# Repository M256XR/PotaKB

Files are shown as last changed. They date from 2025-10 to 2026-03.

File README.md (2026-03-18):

# PotaKB

XIAO nRF52840ベースのワイヤレスキーボード・マウス複合デバイス。

## 概要

- **MCU**: Seeed XIAO nRF52840
- **キー数**: 65キー（8×8マトリクス × MCP23017 + 直接接続2キー）
- **接続**: Bluetooth LE（3スロット独立切替）/ USB HID
- **スティック**: アナログスティックによるマウス操作・スクロール（EMAスムージング）
- **設定**: Web Configuratorからリアルタイム書き換え（BLE / USB Serial）

## 主な機能

### Bluetooth
- **3スロット独立接続**（PotaKB-1 / PotaKB-2 / PotaKB-3）
  - スロットごとに固有のBLEアドレスとボンドDBを持つ → 同一PCで複数スロット使用可
  - スロット別LEDカラー：BT1=青 / BT2=水色 / BT3=マゼンタ
- **高速通信**: `BANDWIDTH_MAX`（hvn_qsize=3）+ 接続インターバル7.5ms → 約500Hz
- BT中にUSBを刺すと自動でUSBモードに切替

### USB
- HID Resolution Multiplier対応（対応OSで高精度スクロール）
- VID=`0x239A` / PID=`0x8029`

### その他
- 一定時間無操作でLEDオフ（スリープ）、操作で即復帰
- バッテリー残量通知（BLE Battery Service）
- フラッシュへのキーマップ・設定の永続保存

## ディレクトリ構成

```
program/PotaKB_fw/
├── PotaKB_fw.ino          ファームウェア (Arduino / nRF52 core)
├── keymap.h               キーマップ定義・デフォルト設定値
└── PotaKB_Configurator/   Web設定ツール (BLE + USB Serial対応)
    ├── index.html
    ├── style.css
    └── script.js

tools/
├── .arduino-user/         カスタムライブラリ（改造済み Bluefruit52Lib）
├── build.ps1              ビルドスクリプト
├── flash.ps1              フラッシュスクリプト
├── setup.ps1              環境セットアップ
└── arduino-cli.yaml       arduino-cli設定

kicad/                     KiCAD回路図・PCBデータ
stl/                       3Dプリント用STLモデル
SPEC.md                    ファームウェア仕様書
```

## ビルド環境

arduino-cli を使用（Arduino IDE不要）。

### 初回セットアップ

```
tools/1_setup.bat
```

ボードパッケージ（Seeeduino nRF52）と依存ライブラリを自動インストール。

### ビルド・フラッシュ

```
tools/2_build.bat   # コンパイル
tools/3_flash.bat   # USB Serial DFUでフラッシュ
```

### 依存ライブラリ（tools/.arduino-user/libraries に同梱）

- `Bluefruit52Lib`（スロット別ボンドDB対応に改造）
- `Adafruit_MCP23017_Arduino_Library`
- `Adafruit_BusIO`

## Configuratorの使い方

`program/PotaKB_fw/PotaKB_Configurator/index.html` をブラウザ（Chrome / Edge）で開く。

- **Bluetooth接続**: デバイス名 `PotaKB-1` / `PotaKB-2` / `PotaKB-3` で接続
- **USB Serial接続**: VID=`0x239A` / PID=`0x8029` で接続
- キーをクリックして選択し、パレットまたはキー入力で割り当て
- 接続時にバッテリー残量を自動取得

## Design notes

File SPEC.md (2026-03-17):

# PotaKB v2.0 ファームウェア仕様書

## 1. ハードウェア構成（固定）

### MCU
- **XIAO nRF52840** (Arm Cortex-M4, nRF52840)

### ピン配置

| 機能 | ピン | 備考 |
|---|---|---|
| スティック（物理X軸） | A2 | PCBミスによりY動作として扱う |
| スティック（物理Y軸） | A3 | PCBミスによりX動作として扱う |
| Backボタン | D6 | INPUT_PULLUP, LOW=押下 |
| Nextボタン | D10 | INPUT_PULLUP, LOW=押下 |
| 電源スイッチ | D7 | INPUT_PULLUP, LOW=ON（HIGHでシステムオフ） |
| パワーLED | D0 | PWM出力 |
| BT状態LED | D1 | PWM出力 |
| 内蔵RGB LED | LED_RED / GREEN / BLUE | 負論理（255=消灯、0=最大輝度） |
| バッテリー電圧 | PIN_VBAT + VBAT_ENABLE | 分圧回路 (1MΩ / 510kΩ) |

### キーマトリクス
- **I/Oエクスパンダ**: MCP23017 (I2C, 400kHz)
- **構成**: 8行 × 8列 = 最大64キー（実装63キー）
  - GPA[0:7]: 行（INPUT_PULLUP）
  - GPB[8:15]: 列（OUTPUT）
- **直接接続キー**: Back (D6), Next (D10) — 計65キー

---

## 2. キーシステム

### 2.1 レイヤー構成

**レイヤー数: 4**（コンパイル時定数 `NUM_LAYERS` で変更可能）

| レイヤー | 名前 | 用途 |
|---|---|---|
| 0 | Base | 通常入力（英字・数字・記号） |
| 1 | Lower | 矢印キー・ページ操作・F1-F12 |
| 2 | Raise | 将来拡張用（デフォルト全KC_TRNS） |
| 3 | Adjust | 設定系（キャリブレーション・リセット・モード切替） |

**レイヤー優先度**: 番号が大きいほど優先（QMK準拠）
複数レイヤーが同時アクティブな場合、最も番号が大きいアクティブレイヤーから検索。

### 2.2 レイヤー操作キーコード

| キーコード | 値 | 動作 |
|---|-----|---|
| `MO(n)` | 0x5000 + n | 押している間だけレイヤーnをアクティブ（QMKのMO相当） |
| `TG(n)` | 0x5010 + n | 押すたびにレイヤーnのON/OFFを切り替え |
| `DF(n)` | 0x5020 + n | デフォルトレイヤーをnに変更（Flash保存） |

### 2.3 特殊キーコード

| キーコード | 値 | 動作 |
|---|-----|---|
| `KC_NO` | 0x0000 | 何もしない |
| `KC_TRNS` | 0xFFFF | 透過（下のレイヤーのキーを使用） ※KC_NOと別値 |
| `SW_MODE` | 0x4001 | USB / Bluetoothモード切替 |
| `KC_CALIBRATE` | 0x4002 | スティックキャリブレーション実行 |
| `KC_RESET` | 0x4003 | キーマップ・設定をデフォルトに戻してリセット |
| `KC_REBOOT` | 0x4004 | 単純リセット（設定保持） |

### 2.4 マウスキーコード

| キーコード | 値 | 動作 |
|---|-----|---|
| `KC_MS_UP` | 0x2001 | カーソル上移動 |
| `KC_MS_DOWN` | 0x2002 | カーソル下移動 |
| `KC_MS_LEFT` | 0x2003 | カーソル左移動 |
| `KC_MS_RIGHT` | 0x2004 | カーソル右移動 |
| `KC_MS_BTN1` | 0x2005 | 左クリック |
| `KC_MS_BTN2` | 0x2006 | 右クリック |
| `KC_MS_BTN3` | 0x2007 | 中クリック |
| `KC_MS_BTN4` | 0x2008 | 戻る |
| `KC_MS_BTN5` | 0x2009 | 進む |
| `KC_MS_SCR_UP` | 0x200A | スクロールアップ |
| `KC_MS_SCR_DOWN` | 0x200B | スクロールダウン |

### 2.5 デバウンス

- **方式**: タイムスタンプ方式（QMK Eager Debounce準拠）
- **時間**: 5ms（`DEBOUNCE_MS` で変更可能）
- 押下・リリース両方にデバウンスを適用

---

## 3. アナログスティック

### 3.1 軸マッピング（PCBミス補正）

```
analogRead(A2) → 論理Y軸（上下）
analogRead(A3) → 論理X軸（左右）
```

### 3.2 動作モード

**モードA（Base レイヤー）: マウスカーソル**
**モードB（Lower レイヤー）: スクロール**

レイヤーの状態によってモードが切り替わる。

### 3.3 速度計算（deltaTime方式）

ガクガクの根本原因はBLE/USBで報告間隔が違うのに固定倍率を使っていたこと。
実際の経過時間を使うことでBLEでもUSBでも同じ動きになる。

```
// 毎ループ
deltaTime = 現在時刻 - 前回更新時刻  [ms]

stickX = analogRead(A3) - center_x   // 論理X
stickY = analogRead(A2) - center_y   // 論理Y

if abs(stickX) < deadzone → stickX = 0
if abs(stickY) < deadzone → stickY = 0

// 速度 = (傾き / 最大傾き) の二乗 × 最大速度  [px/ms]
speed_x = sign(stickX) * (abs(stickX) / 511)^2 * MOUSE_MAX_SPEED
speed_y = sign(stickY) * (abs(stickY) / 511)^2 * MOUSE_MAX_SPEED

// 変位 = 速度 × 経過時間
accumulator_x += speed_x * deltaTime
accumulator_y += speed_y * deltaTime

// 整数部分だけ送信、小数部分は次回に持ち越し
send_x = trunc(accumulator_x)
send_y = trunc(accumulator_y)
accumulator_x -= send_x
accumulator_y -= send_y
```

### 3.4 スムージング

- **方式**: 指数移動平均（EMA）
  ```
  smoothed = alpha * raw + (1 - alpha) * prev_smoothed
  ```
- **alpha**: 0.0〜1.0（1.0 = スムージングなし）
- デフォルト: 0.5（設定で変更可能）
- リングバッファ方式より実装がシンプルで遅延も少ない

### 3.5 キャリブレーション

**自動キャリブレーション（`KC_CALIBRATE` キー）**:
1. キーを押す
2. 青LEDが点滅 → スティックから手を離す（2秒待機）
3. その間の平均値を中心値として保存
4. 緑LED点灯で完了、Flashに保存

**起動時キャリブレーション不要**: 保存済みの中心値を使用。
工場出荷値: center_x = 512, center_y = 512（実測後に `KC_CALIBRATE` で上書き）

### 3.6 スクロールモード（Lowerレイヤー時）

- Y軸 → 縦スクロール
- X軸 → 横スクロール（パン）
- 速度計算はマウスと同じdeltaTime方式
- スクロール量はfloatアキュムレータで管理（小数点以下持ち越し）

---

## 4. HIDレポート送信

### 4.1 送信タイミング

| モード | キーボード | マウス |
|---|---|---|
| USB | 変化時のみ | 1ms間隔（1000Hz） |
| Bluetooth | 変化時のみ | 7.5ms間隔（接続間隔に合わせる） |

マウスは変化がなくても定期送信（ホストのカーソル状態を維持するため）。

### 4.2 BLE接続間隔

- **接続間隔**: 7.5ms（min=max=6 units）
  - ※ 旧FW(5ms)よりわずかに緩めて安定性を優先。体感差はほぼなし。
- **TX Power**: +4dBm

---

## 5. 動作モード

### 5.1 モード一覧

| モード | 説明 |
|---|---|
| USB | TinyUSB HID |
| BT1 | Bluetoothペアリング先1 |
| BT2 | Bluetoothペアリング先2 |
| BT3 | Bluetoothペアリング先3 |

### 5.2 モード切替

- `SW_MODE` キー（1回押すたびに USB→BT1→BT2→BT3→USB と循環）
- 現在のモードをFlashに保存（再起動後も維持）

### 5.3 BT複数台の仕組み

- nRF52840のボンド情報をスロット0〜2に保存
- 各スロットに接続先のアドレス・鍵を保持
- 未ペアリングのスロットに切替えたらアドバタイズ開始（新規ペアリング待ち）
- ペアリング済スロットなら直接再接続

### 5.4 各モードのLED表示

| 状態 | パワーLED | BT LED | RGB LED |
|---|---|---|---|
| USB接続中 | 点灯 | 消灯 | 緑 |
| BT接続中 | 点灯 | 点灯 | 青 |
| BTアドバタイズ中 | 点灯 | 点滅 | 青（点滅） |
| スリープ | 消灯 | 消灯 | 消灯 |
| キャリブレーション中 | — | 点滅 | 青点滅 |
| リセット実行 | — | — | 紫（点滅） |

---

## 6. 電源管理

### 6.1 スリープ

- **System-ON sleep**: 無操作 `SLEEP_TIMEOUT`(ms) 後に移行
  - BLEスタックは維持（Bluetooth接続継続）
  - LED消灯
  - キー入力・スティック操作で即復帰
- **System-OFF sleep**: 電源スイッチ(D7)がHIGHになったとき
  - 完全電源断（`NRF_POWER->SYSTEMOFF = 1`）
  - 電源スイッチを押し直すと再起動

### 6.2 バッテリー

- 計測: 起動時 + 接続時 + 60秒ごと
- BLE Battery Service (BAS) で報告: 5%刻み
- 計算式: ADC値から実電圧を算出し、放電カーブで%変換

---

## 7. Flashストレージ（LittleFS）

| ファイル | 内容 |
|---|---|
| `/keymap.bin` | カスタムキーマップ（`NUM_LAYERS × LAYOUT_KEY_COUNT × 2` bytes） |
| `/config.bin` | 設定値（Config構造体、マジックナンバーで有効性検証） |

起動時にファイルが存在しない・マジックが不正 → デフォルト値を使用。

### Config構造体（新設計）

```c
struct Config {
  uint8_t  version;              // 構造体バージョン（互換性チェック用）
  uint16_t stick_center_x;       // スティックX中心値
  uint16_t stick_center_y;       // スティックY中心値
  uint16_t stick_deadzone;       // デッドゾーン（ADC値）
  float    stick_ema_alpha;      // スムージング係数 (0.0〜1.0)
  float    mouse_max_speed;      // マウス最大速度 [px/ms]
  float    scroll_max_speed;     // スクロール最大速度 [tick/ms]
  uint32_t sleep_timeout_ms;     // スリープまでの時間
  uint8_t  led_brightness;       // LED輝度 (0〜255)
  uint16_t blink_interval_ms;    // BT点滅間隔
  uint32_t magic;                // 0x504F5441 = "POTA"
};
```

---

## 8. Configurator（新設計）

### 8.1 通信プロトコル

BLE GATT + USB Serialの両対応。

**サービス UUID**: `adaf0001-c332-42a8-93bd-25e905756cb8`

| Characteristic | UUID | 権限 | 内容 |
|---|---|---|---|
| Keymap | `adaf0002-...` | READ / WRITE | キーマップバイナリ |
| Config | `adaf0003-...` | READ / WRITE | Config構造体バイナリ |

USBシリアルコマンド（改行区切り）:

```
READ_KEYMAP    → キーマップをバイナリ返送
WRITE_KEYMAP   → 次にバイナリを受信
READ_CONFIG    → Config構造体をバイナリ返送
WRITE_CONFIG   → 次にバイナリを受信
GET_BATTERY    → "BATTERY:xx\n" 返送
CALIBRATE      → キャリブレーション実行
```

### 8.2 Configurator（Web アプリ）

- キーマップエディタ（タブでレイヤー切替）
- Config設定スライダー
- スティックキャリブレーションボタン
- BLE / USB Serial 両対応
- ローカル保存・読み込み

---

## 9. ファイル構成

```
PotaKB_fw/
├── PotaKB_fw.ino     メインファームウェア
├── keymap.h          ハードウェア定数 + デフォルトキーマップ
PotaKB_Configurator/
├── index.html
├── script.js
└── style.css
```

---

## 10. 確定事項

| 項目 | 決定値 | 備考 |
|---|---|---|
| レイヤー数 | **2** | ハードウェア制約（FNキー1個） |
| マウス速度カーブ | **二乗** | デッドゾーン付近は遅く、端に行くほど速い |
| スクロール切替 | **レイヤー連動** | Lower時スティック=スクロール。KC_MS_SCR_UP/DOWNは全レイヤーで使用可 |
| BTペアリング | **3台切替** | BT1/BT2/BT3 + USB の計4モード |
| 開発環境 | **Arduino + Adafruit nRF52 core** | nRF5 SDK+SoftDeviceのラッパー。USB HIDはTinyUSB |

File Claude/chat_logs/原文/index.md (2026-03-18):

# PotaKB セッション索引

## セッション別索引

### Session04 (2026-03-18) - 2026-03-18_Session04.txt
- L1: BLEスロット別ボンドDB分離（bonding.cpp: bond_set_slot()追加、per-slotディレクトリ）
- L80: USB自動切替エッジ検出（prev_usb_mounted フラグ）
- L120: スリープ復帰バグ修正（wakeUp()でaccumulator/lastStickUpdateTimeリセット）
- L160: Configurator修正（namePrefix BLEフィルタ、35バイトconfig読み込み、自動バッテリー取得）
- L220: GitHub push・README更新・GitHub Pages(M256XR.github.io/poke)更新

### Session03 (2026-03-18) - 2026-03-18_Session03.txt
- L1: script.js キャリブレーション関数群実装（calibrateDevice/calibLoop/calibApply等）
- L50: keyboard-layout.json（KLE）解析・Configuratorキービジュアルを実物レイアウトに修正
- L120: FW書き込み後フリーズ → MCP23017 I2Cバスロックアップ診断・initMCP()にリカバリ追加
- L200: キャリブ中カーソルが動く → CALIB_START/END FWコマンド追加・updateStick()フラグ対応
- L250: キャリブ後キー無反応 → calibApply()がsaveToDevice()でキーマップ上書きしてた → config保存のみに修正

### Session02 (2026-03-18) - (要約のみ、原文なし)
- 実機テスト実施: スティック上下反転・USB起動しない・全キー無反応バグ修正
- 基本動作確認済み: キー入力・スティック（USB/BT両対応）

### Session01 (2026-03-18) - 2026-03-18_Session01.txt
- L1: 既存FWの問題分析（KC_TRNS=KC_NO バグ、スティック逆方向、ガクガク原因特定）
- L30: FW v2.0設計・仕様書(SPEC.md)作成
- L80: ハードウェア確認・PCBミス（X/Y逆配線）確認
- L100: FW v2.0フルリライト実施（keymap.h + PotaKB_fw.ino）
- L200: Configurator v2.0フルリライト（index.html / style.css / script.js）
- L280: キー入力キャプチャ機能追加（EVENT_CODE_TO_HID マッピング）
- L310: GitHub push・README修正・セッション管理システム導入

---

## トピック別索引

### スティック
- X/Y逆配線（PCBミス）確認・補正方針: S01 L80
- deltaTime方式速度計算: S01 L100
- EMAスムージング採用: S01 L100
- キャリブレーション機能（Configuratorモーダル + CALIB_START/END）: S03 L1
- stick_range_x/y（Config v2, 34バイト）: S03 L1
- I2Cバスロックアップリカバリ: S03 L120

### キーマップ・レイヤー
- KC_TRNS=0xFFFF / KC_NO=0x0000 バグ修正: S01 L1
- MO(n)方式レイヤーキー採用: S01 L100

### Bluetooth
- BT1/BT2/BT3+USB 4モード設計: S01 L30
- BLE接続間隔 7.5ms設定: S01 L100
- スロット別ボンドDB分離（bonding.cpp bond_set_slot）: S04 L1
- BLEフィルタ namePrefix 対応（PotaKB-1/2/3）: S04 L160

### Configurator
- v2.0フルリライト: S01 L200
- キー入力キャプチャ機能: S01 L280
- Config 30バイト packed構造体: S01 L200
- Config 34バイト v2（stick_range_x/y追加）: S03 L1
- Config 35バイト v3（scroll_invert追加）: S04（via S04スクロール反転）
- キービジュアル実物レイアウト修正（KLEから）: S03 L50
- キャリブレーションモーダルUI: S03 L1
- USB切断イベント検知: S03 L1
- USB Config読み込み35バイト修正（RangeError fix）: S04 L160
- BLE/USB接続時バッテリー自動取得: S04 L160

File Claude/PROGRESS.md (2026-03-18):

# PotaKB 進捗管理

## 現在のフェーズ

**v2.0 実機テスト中**

## 現在の作業箇所

BLE多スロット・USB hi-resスクロール・各種バグ修正完了。GitHub pushおよびGitHub Pages更新済み。主要機能は実機動作確認済み。

## フェーズ完了状況

| フェーズ | 状態 | 内容 |
|---|---|---|
| ハードウェア設計 | ✅ 完了 | PCB・回路図・3Dモデル |
| FW v1.x | ✅ 完了（旧） | `old_fw/` に保管 |
| FW v2.0 リライト | ✅ 完了 | バグ修正・アーキテクチャ刷新 |
| Configurator v2.0 | ✅ 完了 | フルリライト |
| 実機テスト | 🔄 進行中 | 基本動作確認済み |
| BT複数台ボンド管理 | ✅ 完了 | スロット別アドレス・ボンドDB分離で解決 |

## 未解決・要テスト項目

- [x] マウス操作のガクガク修正が実機で効いているか確認（deltaTime方式）← BT接続で動作確認済み
- [x] スティック逆方向バグが解消されているか確認 ← 上下反転を実機で発見・修正済み
- [ ] KC_TRNSレイヤー透過が正しく動作するか確認
- [ ] BT1/BT2/BT3モード切替の動作確認
- [ ] Configurator: BLE接続・キーマップ読み書き確認
- [ ] Configurator: USB Serial接続・コマンド確認
- [ ] Configurator: キー入力キャプチャ機能の動作確認
- [ ] キャリブレーション機能の動作確認（実装済み・未テスト）

## v2.0 主要変更点（参考）

| 修正項目 | 旧 | 新 |
|---|----|----|
| KC_TRNS vs KC_NO | 同じ0x0000（バグ） | KC_TRNS=0xFFFF、KC_NO=0x0000 |
| マウス速度 | 固定5倍補正 | velocity × deltaTime |
| スムージング | リングバッファ(SMOOTHING_SAMPLES=2) | EMA(alpha=0.4) |
| スティックX/Y | コード内で混乱 | A2→論理Y、A3→論理Xを明示 |
| BTモード | 1台のみ | BT1/BT2/BT3+USB 4モード |
| モード保存 | なし | mode.binにFlash保存 |
| レイヤーキー | L_LOWER固定値 | MO(n)方式 |

---

## 直近の決定事項ログ

### 2026-03-18（session05）
- BLEスロット別ボンドDB分離（bonding.cpp 改造）
  - 同一PCで複数スロットを使うとボンドファイルが同一MACで上書きされLTKミスマッチ → HID無応答が根本原因
  - `bond_set_slot(slot)` でアクティブディレクトリを `/adafruit/bond_prph_1/` 等に切り替え
  - `startAdvertising()` 呼び出し前に `bond_set_slot(btSlot)` を追加
- USB自動切替: エッジ検出方式に変更
  - `prev_usb_mounted` フラグで立ち上がりエッジのみ検出 → USB刺しながらBTモードに手動切替してもループしない
- スリープ復帰バグ修正（FW: wakeUp()）
  - スリープ中に `lastStickUpdateTime` が凍結→巨大dt→acc_mouseが±127に即到達→操作不能
  - `wakeUp()` で `lastStickUpdateTime = millis()` + 全accumulator/smoothingをゼロリセット
  - `prev_kb_mod/keys/mouse_btn` も 0xFF にリセット（ゴースト入力防止）
- Configurator 修正
  - BLEフィルタ: `{ name: 'PotaKB' }` → `{ namePrefix: 'PotaKB' }`（PotaKB-1/2/3対応）
  - USB Config読み込みサイズ: 34→35バイト（DataView RangeError修正）
  - BLE/USB接続時にバッテリー残量を自動取得
- GitHub push・README更新・GitHub Pages(M256XR.github.io/poke)のConfiguratorを最新版に更新

### 2026-03-18（session04・続き3）
- スクロールモメンタム（慣性）実装（FW）
  - スティックがデッドゾーン内のとき、EMAで即ゼロではなく半減期200msの指数減衰
  - スティックが動いているときはEMAで速度追従（変更なし）
  - 定数: 0.0035/ms = ln(2)/200ms
  - 効果: スティックを離した後もスクロールがなめらかに減速
- スクロール初期速度を 0.06 → 0.02 tick/ms に変更（速すぎた）
- スクロール反転が効かない件: コードは正しい。Configuratorで「デバイスへ保存する」が必要

### 2026-03-18（session04・続き2）
- Arduino IDEなしの書き込み環境を `tools/` に構築
  - `setup.ps1`: arduino-cli DL + Adafruit nRF52 コア + ライブラリ一括セットアップ（tools/内に閉じ込め）
  - `build.ps1`: コンパイル（FQBN: adafruit:nrf52:Seeed_XIAO_nRF52840）
  - `flash.ps1`: シリアルDFU書き込み（COMポート自動検出 or -Port 指定）
  - `flash_uf2.ps1`: UF2ブートローダー経由書き込み（XIAO_BOOTドライブ自動検出）

### 2026-03-18（session04・続き）
- スクロール方向反転設定を追加（Config + Configurator）
  - Config struct に `scroll_invert`(uint8) 追加 → 35バイト、CONFIG_VERSION=3
  - magic オフセット 30→31 に移動
  - Configurator「スクロール方向を反転」チェックボックス追加
- スクロールスムージング改善（FW）
  - `smooth_scroll_v / smooth_scroll_h` グローバル変数を追加
  - スクロール速度にEMA適用（`stick_ema_alpha` を流用）
  - マウスモード中はスクロール速度変数をリセット（モード切替時バースト防止）
  - 効果: 速度変化が徐々になるため整数HIDステップの間隔が均等化→カクつき軽減

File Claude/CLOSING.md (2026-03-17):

# PotaKB セッション終了処理

「終了処理して」と言われたら以下を自動で実行すること。

---

## 手順

1. **セッション原文を保存**
   ```
   python Claude/extract_session.py
   ```
   → `Claude/chat_logs/原文/YYYY-MM-DD_SessionNN.txt` に保存される

2. **PROGRESS.md 更新**（原文保存後に実施）
   - 「現在の作業箇所」を今日の作業内容に合わせて更新
   - 「直近の決定事項ログ」に今日の日付とセッション番号で決定事項を追記

3. **index.md 更新**（原文ファイルのL行番号を参照しながら）
   - `Claude/chat_logs/原文/index.md` のセッション別索引に今回のセッションを追記
   - 主要トピックのL行番号はおおよその目安でOK
   - トピック別索引に新規トピックがあれば追記

4. **ドキュメント更新確認**
   - 以下のファイルに今回の変更を反映すべきか確認する：
     - `README.md`
     - `SPEC.md`（仕様変更・確定事項があった場合）
     - `Claude/CLAUDE.md`（設計決定の追加・変更があった場合）
   - 更新が必要なら該当箇所を修正する

5. **session_close.py 実行**（上記がすべて完了してから）
   ```
   python Claude/session_close.py "Docs: sessionNN終了処理・PROGRESS/index更新"
   ```
   → PROGRESS.md の古いログを archive/ に移動（直近4件残す）
   → git add -A + commit + push

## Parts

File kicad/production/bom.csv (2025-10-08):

Designator | Footprint | Quantity | Value | LCSC Part #
C1, C2 | 0603 | 2 | C_Small
D1, D10, D11, D12, D13, D14, D15, D16, D17, D18, D19, D2, D20, D21, D22, D23, D24, D25, D26, D27, D28, D29, D3, D30, D31, D32, D33, D34, D35, D36, D37, D38, D39, D4, D40, D41, D42, D43, D44, D45, D46, D47, D48, D49, D5, D50, D51, D52, D53, D54, D55, D56, D57, D58, D59, D6, D60, D61, D62, D63, D7, D8, D9 | D_SOD-323 | 63 | D_Small
D64, D65 | 0805 | 2 | LED_Small
J4 | LowHeightJoyStickWithButton | 1 | Stick
R1, R2, R3, R4 | 0603 | 4 | R_Small
SW1, SW62 | SW_THBP07-043CW | 2 | SW_Push
SW10, SW11, SW12, SW13, SW14, SW15, SW16, SW17, SW18, SW19, SW2, SW20, SW21, SW22, SW23, SW24, SW25, SW26, SW27, SW28, SW29, SW3, SW30, SW31, SW32, SW33, SW34, SW35, SW36, SW37, SW38, SW39, SW4, SW40, SW41, SW42, SW43, SW44, SW45, SW46, SW47, SW48, SW49, SW5, SW50, SW51, SW52, SW53, SW54, SW55, SW56, SW57, SW58, SW59, SW6, SW60, SW61, SW63, SW66, SW67, SW7, SW8, SW9 | SW_Tactile_6x6mm_2Pin_P5.0mm | 63 | SW_Push
SW65 | SW_Slide_SPDT_Angled_CK_OS102011MA1Q | 1 | SW_SPDT
U1 | Seeeduino XIAO-MOUDLE14P-2.54-21X17.8MM | 1 | ~
U2 | SSOP-28_5.3x10.2mm_P0.65mm | 1 | MCP23017_SO

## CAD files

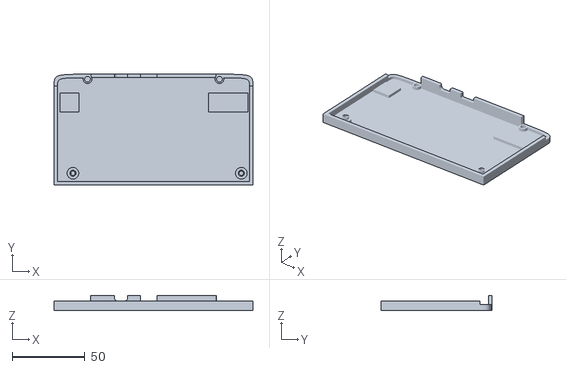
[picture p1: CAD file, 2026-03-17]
kicad/main.stl
136.5 x 76.0 x 10.1

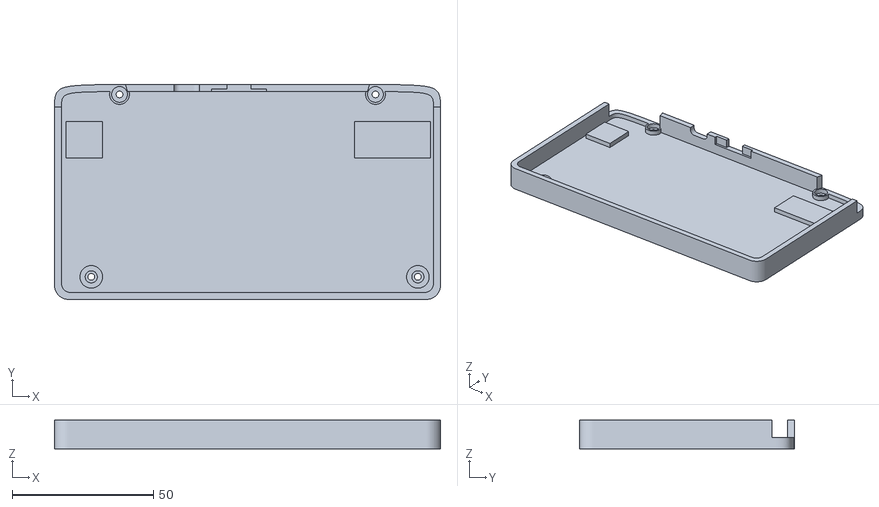
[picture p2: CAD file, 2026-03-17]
stl/main.stl
136.5 x 76.0 x 10.1

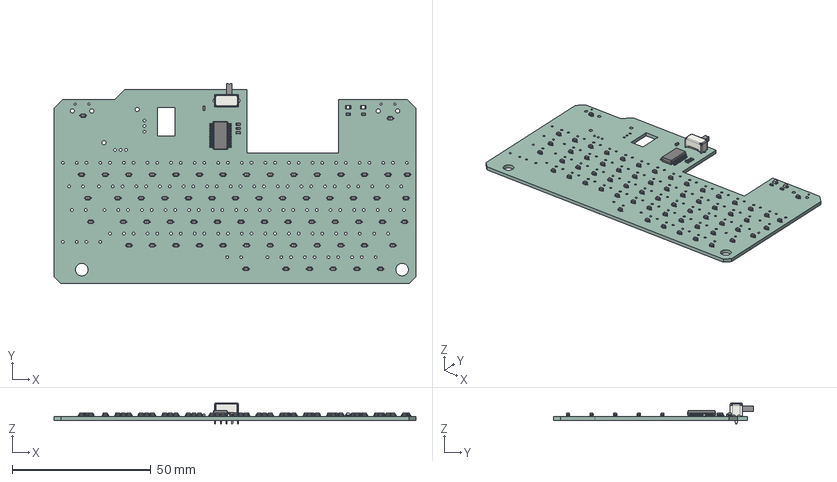
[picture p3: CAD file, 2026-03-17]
kicad/Potable_Keyboard.step
130.5 x 72.1 x 7.50 mm
D_SOD-323 x 63
SSOP-28_5.3x10.2mm_P0.65mm
LED_0805_2012Metric x 2
C_0603_1608Metric x 2
R_0603_1608Metric x 4
SW_Slide_SPDT_Angled_CK_OS102011MA1Q
Potable_Keyboard_PCB

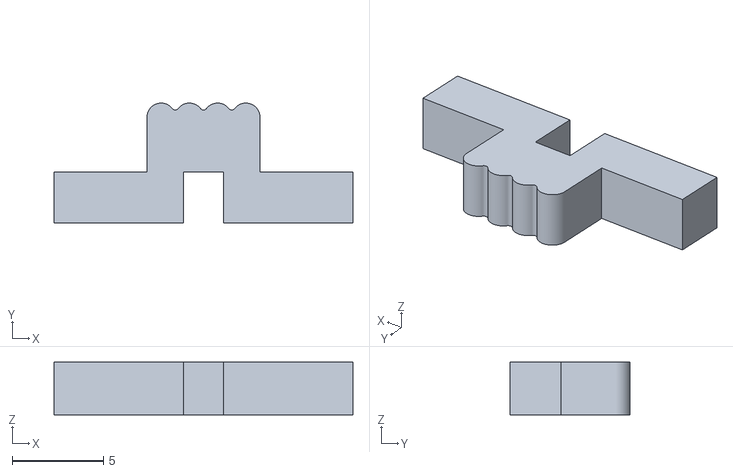
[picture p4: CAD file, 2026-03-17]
stl/powersw.stl
16.4 x 6.57 x 2.90

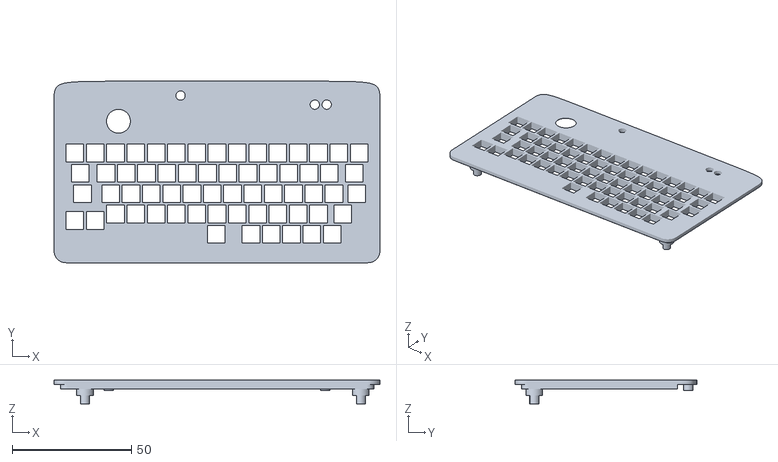
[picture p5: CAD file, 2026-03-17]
stl/top.stl
136.5 x 76.0 x 10.0

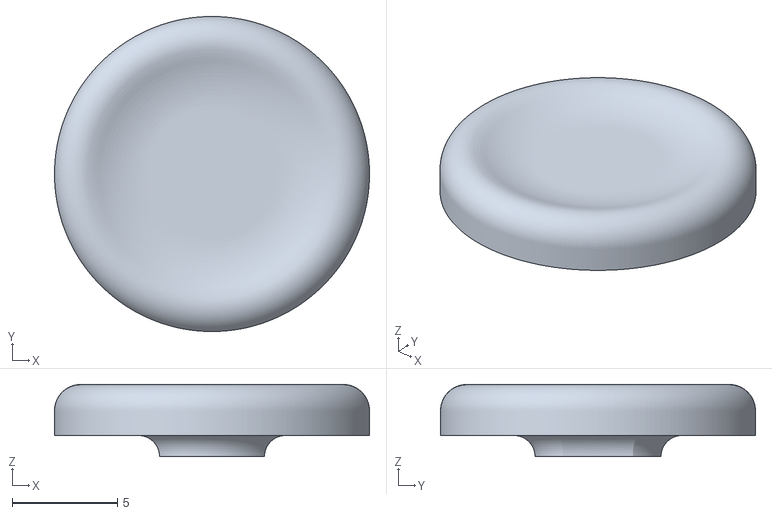
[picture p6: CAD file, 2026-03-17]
stl/stick.stl
15.0 x 15.0 x 3.43

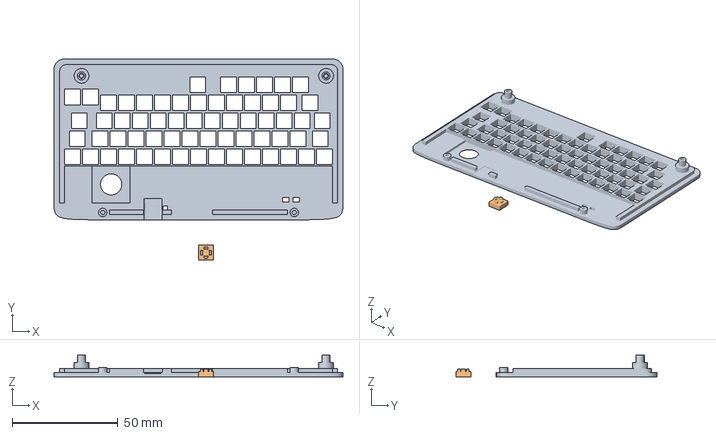
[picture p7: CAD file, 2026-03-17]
stl/L.3mf
136.5 x 95.0 x 10.2 mm
top.stl
sw.stl

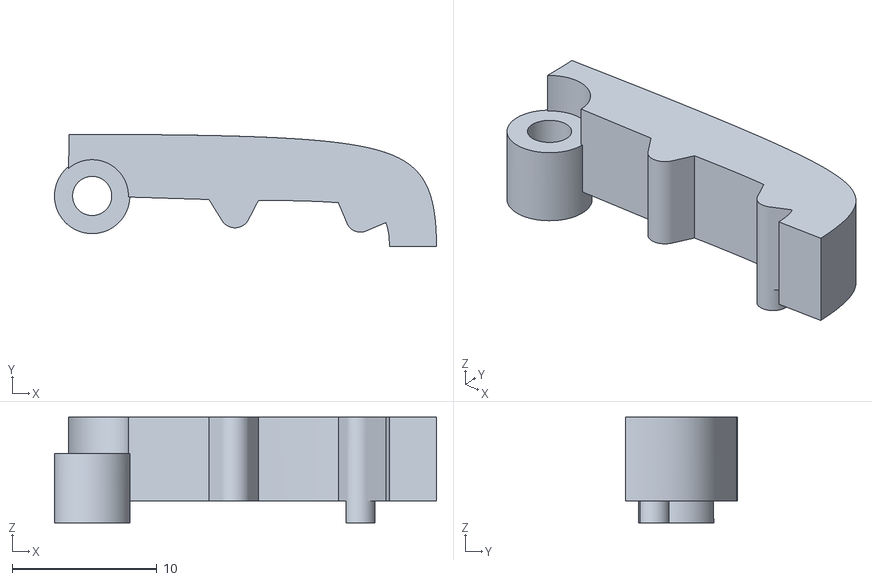
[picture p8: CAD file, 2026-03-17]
stl/R.stl
26.3 x 7.75 x 7.30

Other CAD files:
stl/sw.3mf
stl/L.stl
stl/sw.stl

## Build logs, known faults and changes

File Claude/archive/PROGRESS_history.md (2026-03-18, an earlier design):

# PROGRESS 決定事項ログ アーカイブ

### 2026-03-18（session04）
- キャリブレーション画面のスティック上下逆バグ修正（Configurator）
  - `calibDrawCanvas` でY軸を反転: `py = ((1023-y)/1023)*H`、範囲ボックスも同様
  - 原因: FWでは「Y値大＝上方向」だがキャンバスはY=0が上なので逆になっていた
- 電源OFF状態でUSB接続時に赤ランプ点灯＋スリープ入りするバグ修正（FW）
  - `setup()` の冒頭（`initHardware()`前）で POWER_SW_PIN を確認追加
  - HIGH（OFF状態）なら即 `NRF_POWER->SYSTEMOFF = 1` → LED点灯前に終了
  - USB接続時はSYSTEMOFFがリセットを引き起こすが setup()先頭から再実行されるためLED不点灯

### 2026-03-18（session03）
- スティックキャリブレーション機能を実装（Configurator UI + FWコマンド）
  - Config構造体に stick_range_x/y 追加（30→34バイト、CONFIG_VERSION=2）
  - Configuratorにキャリブレーションモーダル追加（3フェーズ: 中央記録→範囲計測→結果適用）
  - FW: `READ_STICK` / `CALIB_START` / `CALIB_END` シリアルコマンド追加
  - キャリブ中カーソル動く問題 → `CALIB_START` でスティック無効化
  - キャリブ後キー無反応 → `calibApply()` がキーマップも上書きしてた → config のみ保存に修正
- `keyboard-layout.json`（KLE）を元にConfigurator のキービジュアルを実物レイアウトに修正
  - Z行：左2u空白（スティックスペース）+ 11キー + LShift 1.5u
  - 底面：左6u空白 + Space 2.5u + 5キー1u
  - マウスボタン行：Btn1(1.5u) ... 12u gap ... Btn2(1.5u)
- MCP23017 I2Cバスロックアップ対策を `initMCP()` に追加（9クロックリカバリ）
- Configurator: USB切断イベント検知追加
- FW: I2Cリカバリ後もMCPへの書き込みハングでフリーズすることを確認
  - 原因: XIAOリセット時にMCPがI2Cトランザクション中断で詰まる場合あり
  - 対処: XIAOリセットボタンで復帰可能（電源断でも可）

### 2026-03-18（session02）
- 実機テスト実施、以下のバグを発見・修正
  - スティック上下反転 → `acc_mouse_y -= vy * dt` に修正
  - USB起動しない → 起動時USB優先ロジックに修正、USB抜き時saveMode削除
  - 全キー無反応 → 旧FWのkeymap.bin（256B）がフォーマット違いで読まれていた → サイズ・全ゼロチェックで自動削除
  - scanMatrix一括操作（writeGPIOAB/readGPIOAB）動作確認済み（旧FWと同等）
- 基本動作確認済み：キー入力・スティック（USB/BT両対応）

### 2026-03-18（session01）
- FW v2.0 フルリライト実施
  - KC_TRNS=0xFFFF / KC_NO=0x0000 に修正
  - マウス速度をvelocity×deltaTime方式に変更（BT/USB共通）
  - EMAスムージング採用（α=0.4デフォルト）
  - スティックA2→論理Y、A3→論理X（PCBミス補正を明示化）
  - BT1/BT2/BT3+USB 4モード切替実装
  - MO(n)方式のレイヤー操作キー採用
  - Config構造体を新設計（30バイト packed）
- Configurator v2.0 フルリライト
  - ダークテーマ、2カラムレイアウト
  - 物理キーボード入力でキーコード割り当て機能追加
  - BLE + USB Serial 両対応
  - DataViewで30バイトConfig構造体を正確に変換
- セッション管理システム導入（PortaRe0から移植）
- D:\Projects\PotaKB にリポジトリをクローン

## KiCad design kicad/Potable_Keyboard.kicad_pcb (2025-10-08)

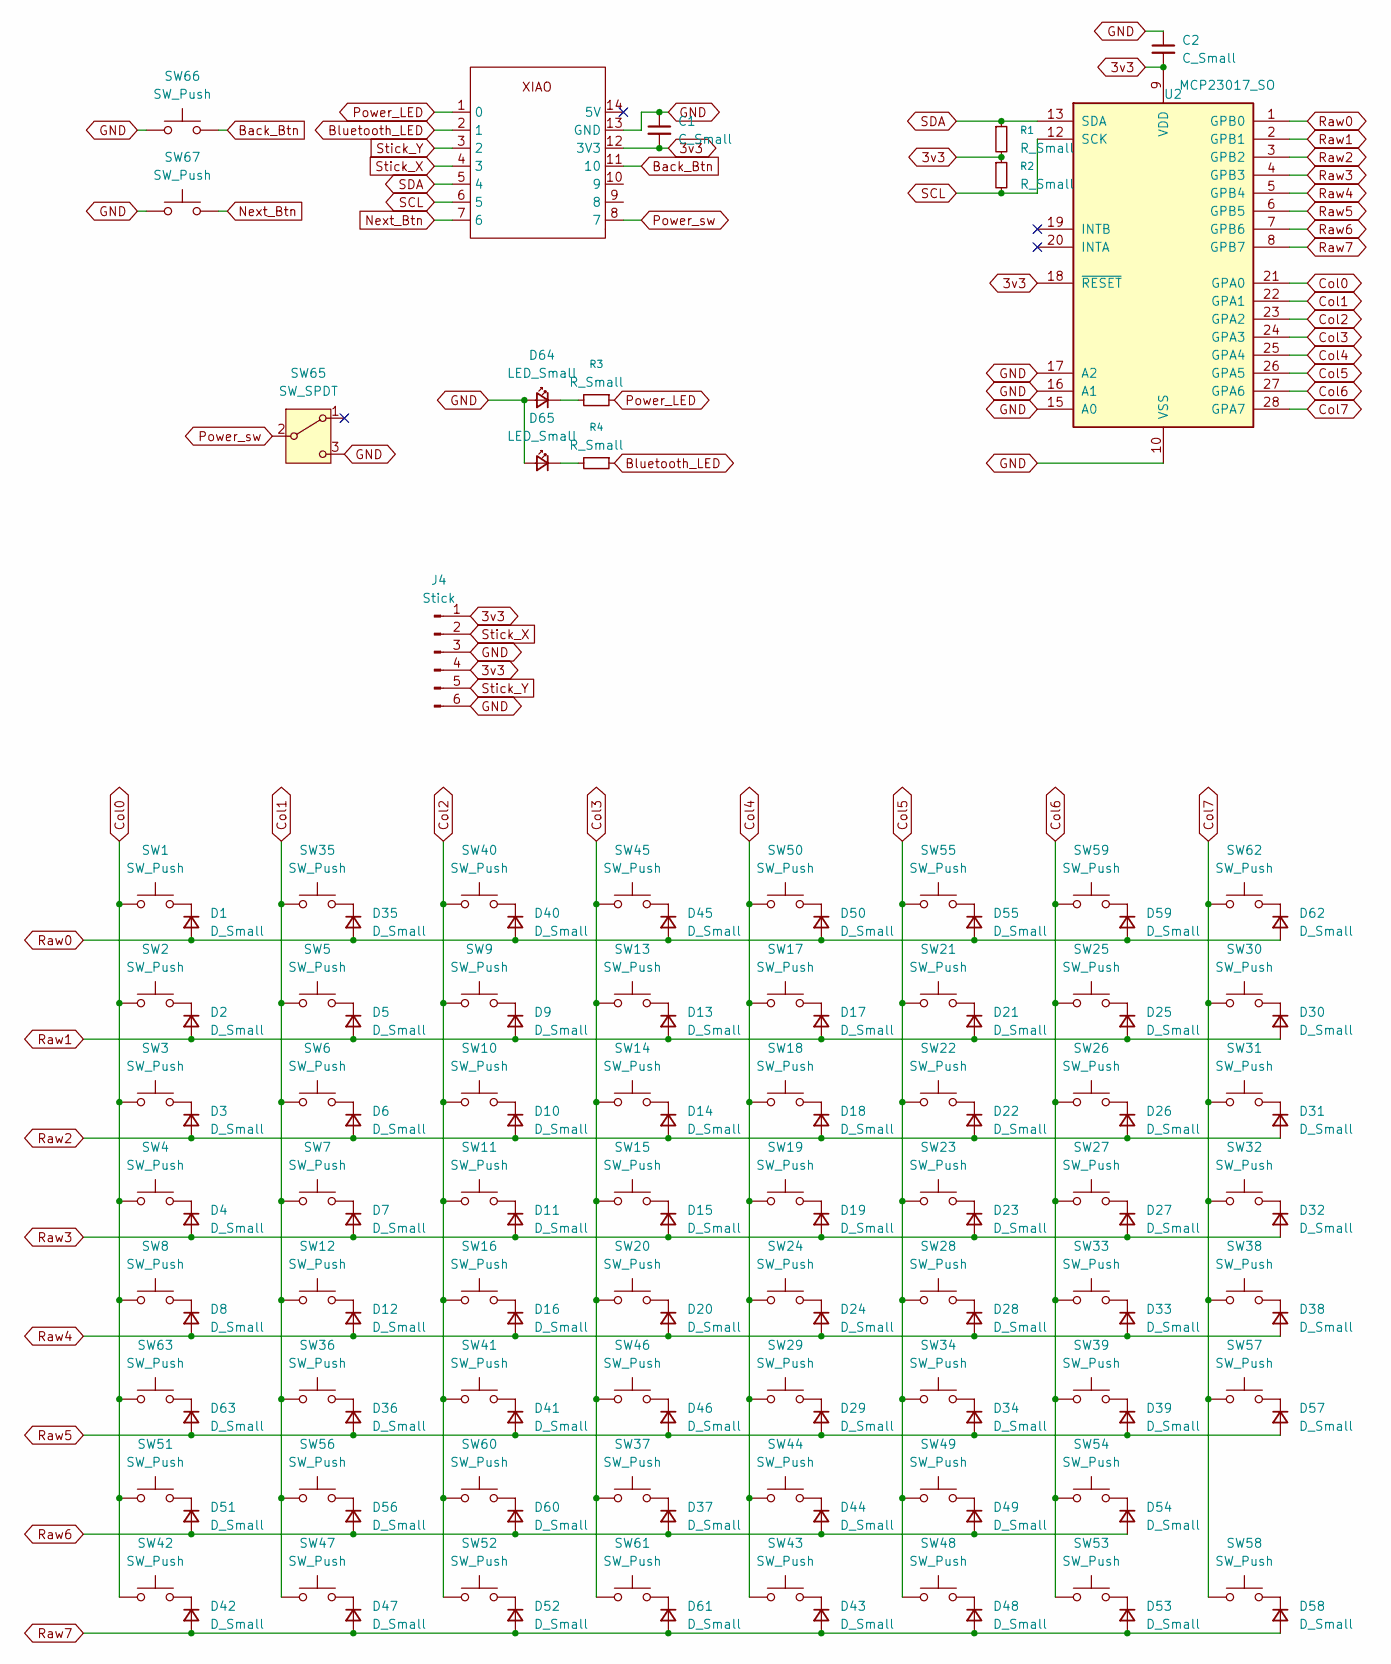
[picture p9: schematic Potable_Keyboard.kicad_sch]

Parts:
C1, C2: C_Small; C_0603_1608Metric_Pad1.08x0.95mm_HandSolder
D1, D2, D3, D4, D5, D6, D7, D8, D9, D10, D11, D12, D13, D14, D15, D16, D17, D18, D19, D20, D21, D22, D23, D24, D25, D26, D27, D28, D29, D30, D31, D32, D33, D34, D35, D36, D37, D38, D39, D40, D41, D42, D43, D44, D45, D46, D47, D48, D49, D50, D51, D52, D53, D54, D55, D56, D57, D58, D59, D60, D61, D62, D63: D_Small; D_SOD-323
D64, D65: LED_Small; LED_0805_2012Metric_Pad1.15x1.40mm_HandSolder
J4: Stick; LowHeightJoyStickWithButton
R1, R2, R3, R4: R_Small; R_0603_1608Metric_Pad0.98x0.95mm_HandSolder
SW1, SW62: SW_Push; SW_THBP07-043CW
SW2, SW3, SW4, SW5, SW6, SW7, SW8, SW9, SW10, SW11, SW12, SW13, SW14, SW15, SW16, SW17, SW18, SW19, SW20, SW21, SW22, SW23, SW24, SW25, SW26, SW27, SW28, SW29, SW30, SW31, SW32, SW33, SW34, SW35, SW36, SW37, SW38, SW39, SW40, SW41, SW42, SW43, SW44, SW45, SW46, SW47, SW48, SW49, SW50, SW51, SW52, SW53, SW54, SW55, SW56, SW57, SW58, SW59, SW60, SW61, SW63, SW66, SW67: SW_Push; SW_Tactile_6x6mm_2Pin_P5.0mm
SW65: SW_SPDT; SW_Slide_SPDT_Angled_CK_OS102011MA1Q
U1: Seeeduino XIAO-MOUDLE14P-2.54-21X17.8MM
U2: MCP23017_SO; SSOP-28_5.3x10.2mm_P0.65mm

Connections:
3v3: C1.2, C2.2, J4.1, J4.4, R1.2, R2.1, U1.12 (3V3), U2.9 (VDD), U2.18 (~RESET)
Back_Btn: SW66.2, U1.11 (10)
Bluetooth_LED: R4.1, U1.2 (1)
Col0: SW1.1, SW2.1, SW3.1, SW4.1, SW8.1, SW42.1, SW51.1, SW63.1, U2.21 (GPA0)
Col1: SW5.1, SW6.1, SW7.1, SW12.1, SW35.1, SW36.1, SW47.1, SW56.1, U2.22 (GPA1)
Col2: SW9.1, SW10.1, SW11.1, SW16.1, SW40.1, SW41.1, SW52.1, SW60.1, U2.23 (GPA2)
Col3: SW13.1, SW14.1, SW15.1, SW20.1, SW37.1, SW45.1, SW46.1, SW61.1, U2.24 (GPA3)
Col4: SW17.1, SW18.1, SW19.1, SW24.1, SW29.1, SW43.1, SW44.1, SW50.1, U2.25 (GPA4)
Col5: SW21.1, SW22.1, SW23.1, SW28.1, SW34.1, SW48.1, SW49.1, SW55.1, U2.26 (GPA5)
Col6: SW25.1, SW26.1, SW27.1, SW33.1, SW39.1, SW53.1, SW54.1, SW59.1, U2.27 (GPA6)
Col7: SW30.1, SW31.1, SW32.1, SW38.1, SW57.1, SW58.1, SW62.1, U2.28 (GPA7)
GND: C1.1, C2.1, D64.2 (A), D65.2 (A), J4.3, J4.6, SW65.3 (C), SW66.1, SW67.1, U1.13 (GND), U2.10 (VSS), U2.15 (A0), U2.16 (A1), U2.17 (A2)
unnamed: D1.1 (K), SW1.2
unnamed: D2.1 (K), SW2.2
unnamed: D3.1 (K), SW3.2
unnamed: D4.1 (K), SW4.2
unnamed: D5.1 (K), SW5.2
unnamed: D6.1 (K), SW6.2
unnamed: D7.1 (K), SW7.2
unnamed: D8.1 (K), SW8.2
unnamed: D9.1 (K), SW9.2
unnamed: D10.1 (K), SW10.2
unnamed: D11.1 (K), SW11.2
unnamed: D12.1 (K), SW12.2
unnamed: D13.1 (K), SW13.2
unnamed: D14.1 (K), SW14.2
unnamed: D15.1 (K), SW15.2
unnamed: D16.1 (K), SW16.2
unnamed: D17.1 (K), SW17.2
unnamed: D18.1 (K), SW18.2
unnamed: D19.1 (K), SW19.2
unnamed: D20.1 (K), SW20.2
unnamed: D21.1 (K), SW21.2
unnamed: D22.1 (K), SW22.2
unnamed: D23.1 (K), SW23.2
unnamed: D24.1 (K), SW24.2
unnamed: D25.1 (K), SW25.2
unnamed: D26.1 (K), SW26.2
unnamed: D27.1 (K), SW27.2
unnamed: D28.1 (K), SW28.2
unnamed: D29.1 (K), SW29.2
unnamed: D30.1 (K), SW30.2
unnamed: D31.1 (K), SW31.2
unnamed: D32.1 (K), SW32.2
unnamed: D33.1 (K), SW33.2
unnamed: D34.1 (K), SW34.2
unnamed: D35.1 (K), SW35.2
unnamed: D36.1 (K), SW36.2
unnamed: D37.1 (K), SW37.2
unnamed: D38.1 (K), SW38.2
unnamed: D39.1 (K), SW39.2
unnamed: D40.1 (K), SW40.2
unnamed: D41.1 (K), SW41.2
unnamed: D42.1 (K), SW42.2
unnamed: D43.1 (K), SW43.2
unnamed: D44.1 (K), SW44.2
unnamed: D45.1 (K), SW45.2
unnamed: D46.1 (K), SW46.2
unnamed: D47.1 (K), SW47.2
unnamed: D48.1 (K), SW48.2
unnamed: D49.1 (K), SW49.2
unnamed: D50.1 (K), SW50.2
unnamed: D51.1 (K), SW51.2
unnamed: D52.1 (K), SW52.2
unnamed: D53.1 (K), SW53.2
unnamed: D54.1 (K), SW54.2
unnamed: D55.1 (K), SW55.2
unnamed: D56.1 (K), SW56.2
unnamed: D57.1 (K), SW57.2
unnamed: D58.1 (K), SW58.2
unnamed: D59.1 (K), SW59.2
unnamed: D60.1 (K), SW60.2
unnamed: D61.1 (K), SW61.2
unnamed: D62.1 (K), SW62.2
unnamed: D63.1 (K), SW63.2
unnamed: D64.1 (K), R3.2
unnamed: D65.1 (K), R4.2
Next_Btn: SW67.2, U1.7 (6)
Power_LED: R3.1, U1.1 (0)
Power_sw: SW65.2 (B), U1.8 (7)
Raw0: D1.2 (A), D35.2 (A), D40.2 (A), D45.2 (A), D50.2 (A), D55.2 (A), D59.2 (A), D62.2 (A), U2.1 (GPB0)
Raw1: D2.2 (A), D5.2 (A), D9.2 (A), D13.2 (A), D17.2 (A), D21.2 (A), D25.2 (A), D30.2 (A), U2.2 (GPB1)
Raw2: D3.2 (A), D6.2 (A), D10.2 (A), D14.2 (A), D18.2 (A), D22.2 (A), D26.2 (A), D31.2 (A), U2.3 (GPB2)
Raw3: D4.2 (A), D7.2 (A), D11.2 (A), D15.2 (A), D19.2 (A), D23.2 (A), D27.2 (A), D32.2 (A), U2.4 (GPB3)
Raw4: D8.2 (A), D12.2 (A), D16.2 (A), D20.2 (A), D24.2 (A), D28.2 (A), D33.2 (A), D38.2 (A), U2.5 (GPB4)
Raw5: D29.2 (A), D34.2 (A), D36.2 (A), D39.2 (A), D41.2 (A), D46.2 (A), D57.2 (A), D63.2 (A), U2.6 (GPB5)
Raw6: D37.2 (A), D44.2 (A), D49.2 (A), D51.2 (A), D54.2 (A), D56.2 (A), D60.2 (A), U2.7 (GPB6)
Raw7: D42.2 (A), D43.2 (A), D47.2 (A), D48.2 (A), D52.2 (A), D53.2 (A), D58.2 (A), D61.2 (A), U2.8 (GPB7)
SCL: R2.2, U1.6 (5), U2.12 (SCK)
SDA: R1.1, U1.5 (4), U2.13 (SDA)
Stick_X: J4.2, U1.4 (3)
Stick_Y: J4.5, U1.3 (2)

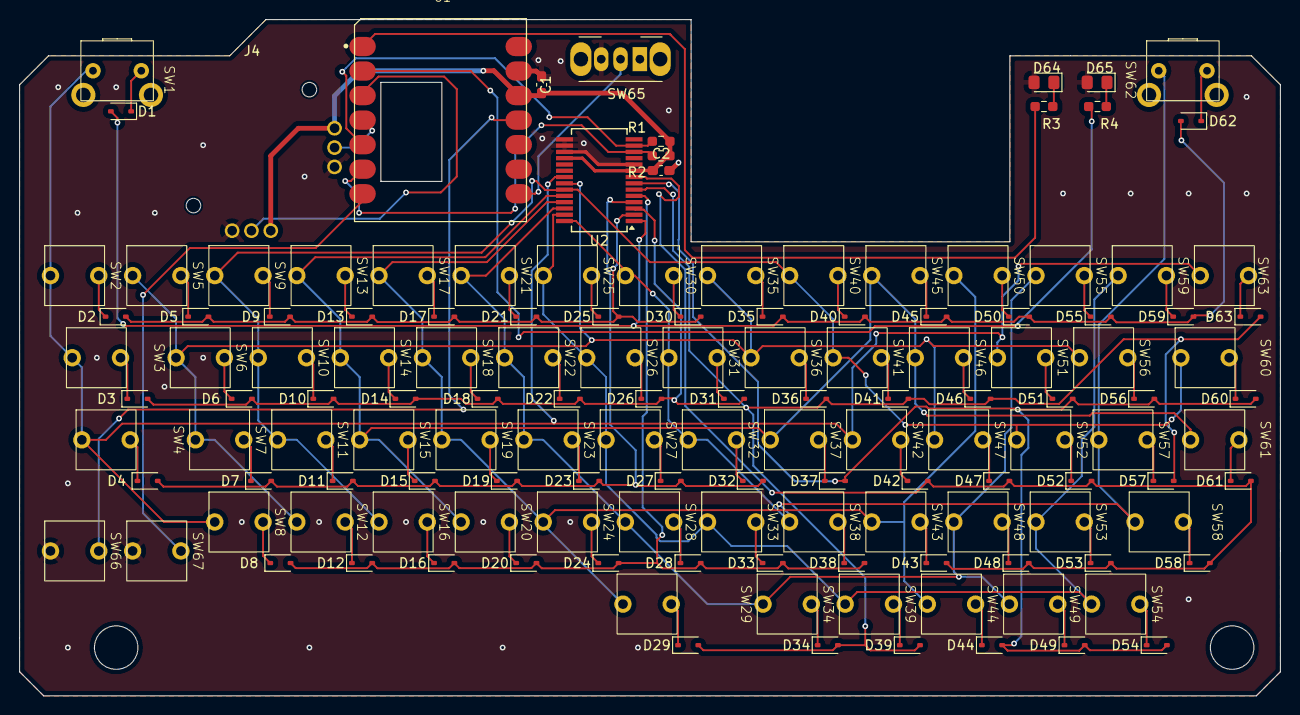
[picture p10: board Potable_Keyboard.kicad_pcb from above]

Board: 2 copper layers, 130.5 x 70.0 mm, 140 parts (0 on the bottom side), 92 nets.

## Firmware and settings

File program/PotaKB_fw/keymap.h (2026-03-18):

// =========================================================================
// PotaKB keymap.h
// ★ ここを編集してキーマップをカスタマイズ ★
// =========================================================================

#pragma once
#include <Adafruit_TinyUSB.h>

// -------------------------------------------------------------------------
// ハードウェア定数（変更不要）
// -------------------------------------------------------------------------
#define ROWS              8
#define COLS              8
#define LAYOUT_KEY_COUNT  65   // 63(matrix) + 2(direct: Back/Next)
#define NUM_LAYERS        2

// -------------------------------------------------------------------------
// キーコード定義
// -------------------------------------------------------------------------

// 何もしない / 透過
#define KC_NO    0x0000   // 何もしない
#define KC_TRNS  0xFFFF   // 下のレイヤーに透過（KC_NOとは別値）

// レイヤー操作
// MO(n): 押している間レイヤーnをアクティブにする
#define MO(n)   (0x5000 | (n))

// USB / Bluetoothモード切替
// SW_MODE: 押すたびに USB→BT1→BT2→BT3→USB と切替
#define SW_MODE  0x4001

// スティックキャリブレーション
#define KC_CALIBRATE  0x4002

// リセット系
#define KC_RESET   0x4003   // キーマップ・設定リセット＋再起動
#define KC_REBOOT  0x4004   // 設定保持のまま再起動

// マウスキー
#define KC_MS_UP    0x2001
#define KC_MS_DOWN  0x2002
#define KC_MS_LEFT  0x2003
#define KC_MS_RIGHT 0x2004
#define KC_MS_BTN1  0x2005   // 左クリック
#define KC_MS_BTN2  0x2006   // 右クリック
#define KC_MS_BTN3  0x2007   // 中クリック
#define KC_MS_BTN4  0x2008   // 戻る
#define KC_MS_BTN5  0x2009   // 進む
#define KC_MS_SCR_UP    0x200A
#define KC_MS_SCR_DOWN  0x200B
#define KC_MS_SCR_LEFT  0x200C
#define KC_MS_SCR_RIGHT 0x200D

// 日本語キーボード固有キー（未定義の場合のみ定義）
#ifndef HID_KEY_INTERNATIONAL1
  #define HID_KEY_INTERNATIONAL1 0x89  // ろ（\ |）
#endif
#ifndef HID_KEY_INTERNATIONAL3
  #define HID_KEY_INTERNATIONAL3 0x87  // ¥ |
#endif
#ifndef HID_KEY_LANG1
  #define HID_KEY_LANG1 0x90  // かな
#endif
#ifndef HID_KEY_LANG2
  #define HID_KEY_LANG2 0x91  // 英数
#endif

// -------------------------------------------------------------------------
// デフォルト設定値
// -------------------------------------------------------------------------
#define DEFAULT_STICK_CENTER_X    512
#define DEFAULT_STICK_CENTER_Y    512
#define DEFAULT_STICK_DEADZONE    75
#define DEFAULT_STICK_RANGE_X     511
#define DEFAULT_STICK_RANGE_Y     511
#define DEFAULT_STICK_EMA_ALPHA   0.4f   // スムージング係数 (0=最大平滑, 1=なし)
#define DEFAULT_MOUSE_MAX_SPEED   0.8f   // px/ms（deltaTime方式）
#define DEFAULT_SCROLL_MAX_SPEED  0.02f  // tick/ms
#define DEFAULT_SLEEP_TIMEOUT_MS  300000UL
#define DEFAULT_LED_BRIGHTNESS    25
#define DEFAULT_BLINK_INTERVAL_MS 600
#define DEFAULT_SCROLL_INVERT     0

// -------------------------------------------------------------------------
// デフォルトキーマップ
// キー順序: 物理レイアウト順（左上から右下）
//
// [0..1]   : 1段目（マウスボタン2個）
// [2..16]  : 2段目（数字行 15キー）
// [17..30] : 3段目（Q行 14キー）
// [31..44] : 4段目（A行 14キー）
// [45..56] : 5段目（Z行 12キー）
// [57..62] : 6段目（6キー）
// [63]     : Nextボタン（D10）
// [64]     : Backボタン（D6）
// -------------------------------------------------------------------------
const uint16_t default_keymap[NUM_LAYERS][LAYOUT_KEY_COUNT] = {

  // =======================================================================
  // [0] Base Layer
  // =======================================================================
  {
    // 1段目 (2キー)
    KC_MS_BTN1, KC_MS_BTN2,

    // 2段目 (15キー)
    HID_KEY_ESCAPE,
    HID_KEY_1, HID_KEY_2, HID_KEY_3, HID_KEY_4, HID_KEY_5,
    HID_KEY_6, HID_KEY_7, HID_KEY_8, HID_KEY_9, HID_KEY_0,
    HID_KEY_MINUS, HID_KEY_EQUAL,
    HID_KEY_INTERNATIONAL1,  // ろ
    HID_KEY_DELETE,

    // 3段目 (14キー)
    HID_KEY_GRAVE,
    HID_KEY_Q, HID_KEY_W, HID_KEY_E, HID_KEY_R, HID_KEY_T,
    HID_KEY_Y, HID_KEY_U, HID_KEY_I, HID_KEY_O, HID_KEY_P,
    HID_KEY_BRACKET_LEFT, HID_KEY_BRACKET_RIGHT,
    HID_KEY_BACKSPACE,

    // 4段目 (14キー)
    HID_KEY_TAB,
    HID_KEY_A, HID_KEY_S, HID_KEY_D, HID_KEY_F, HID_KEY_G,
    HID_KEY_H, HID_KEY_J, HID_KEY_K, HID_KEY_L,
    HID_KEY_SEMICOLON, HID_KEY_APOSTROPHE,
    HID_KEY_BACKSLASH,
    HID_KEY_ENTER,

    // 5段目 (12キー)
    HID_KEY_Z, HID_KEY_X, HID_KEY_C, HID_KEY_V, HID_KEY_B,
    HID_KEY_N, HID_KEY_M,
    HID_KEY_COMMA, HID_KEY_PERIOD, HID_KEY_SLASH,
    HID_KEY_INTERNATIONAL3,  // ¥
    HID_KEY_SHIFT_LEFT,

    // 6段目 (6キー)
    HID_KEY_SPACE,
    HID_KEY_GUI_LEFT,
    HID_KEY_ALT_LEFT,
    HID_KEY_CONTROL_LEFT,
    KC_MS_BTN3,
    MO(1),

    // 直接接続キー
    KC_MS_BTN4,  // Next (D10) = 戻る
    KC_MS_BTN5,  // Back  (D6) = 進む
  },

  // =======================================================================
  // [1] Lower Layer
  // =======================================================================
  {
    // 1段目
    KC_NO, KC_NO,

    // 2段目
    SW_MODE,
    HID_KEY_F1,  HID_KEY_F2,  HID_KEY_F3,  HID_KEY_F4,  HID_KEY_F5,
    HID_KEY_F6,  HID_KEY_F7,  HID_KEY_F8,  HID_KEY_F9,  HID_KEY_F10,
    HID_KEY_F11, HID_KEY_F12,
    KC_NO,
    KC_NO,

    // 3段目
    KC_NO,
    KC_NO, HID_KEY_ARROW_UP,   KC_NO, KC_NO, KC_NO,
    KC_NO, KC_NO, KC_NO, KC_NO, KC_NO,
    KC_NO, KC_NO,
    KC_NO,

    // 4段目
    KC_NO,
    HID_KEY_ARROW_LEFT, HID_KEY_ARROW_DOWN, HID_KEY_ARROW_RIGHT, KC_NO, KC_NO,
    KC_NO, KC_NO, KC_NO, KC_NO,
    KC_NO, KC_NO,
    KC_NO,
    KC_NO,

    // 5段目
    HID_KEY_END, HID_KEY_HOME, HID_KEY_PAGE_UP, HID_KEY_PAGE_DOWN, KC_NO,
    KC_NO, KC_NO,
    KC_NO, KC_NO, KC_NO,
    KC_NO,
    KC_NO,

    // 6段目
    KC_NO, KC_NO, KC_NO, KC_NO, KC_NO,
    MO(1),

    // 直接接続キー
    KC_NO,         // Next = 空き（キャリブレーションはConfigurator経由）
    KC_RESET,      // Back = リセット
  },
};

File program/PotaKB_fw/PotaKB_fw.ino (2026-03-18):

// =========================================================================
// PotaKB Firmware v2.0
// XIAO nRF52840 + MCP23017
// =========================================================================

#include <bluefruit.h>
#include <Wire.h>
#include <Adafruit_MCP23X17.h>
#include <Adafruit_TinyUSB.h>
#include <InternalFileSystem.h>
#include "keymap.h"

using namespace Adafruit_LittleFS_Namespace;

// =========================================================================
// 定数・ピン定義
// =========================================================================

#define STICK_PHYS_X_PIN  A2   // PCBミスにより物理XピンがY動作
#define STICK_PHYS_Y_PIN  A3   // PCBミスにより物理YピンがX動作

#define BACK_BTN_PIN      D6
#define NEXT_BTN_PIN      D10
#define POWER_SW_PIN      D7
#define POWER_LED_PIN     D0
#define BT_LED_PIN        D1

#define DEBOUNCE_MS       5

// BLEモード数
#define BT_SLOT_COUNT     3

// =========================================================================
// ファイル名
// =========================================================================
static const char* KEYMAP_FILE  = "/keymap.bin";
static const char* CONFIG_FILE  = "/config.bin";
static const char* MODE_FILE    = "/mode.bin";

// =========================================================================
// 設定構造体
// =========================================================================
#pragma pack(push, 1)
struct Config {
  uint8_t  version;
  uint16_t stick_center_x;
  uint16_t stick_center_y;
  uint16_t stick_deadzone;
  uint16_t stick_range_x;     // offset 7  スティックX軸の最大変位
  uint16_t stick_range_y;     // offset 9  スティックY軸の最大変位
  float    stick_ema_alpha;   // offset 11
  float    mouse_max_speed;   // offset 15
  float    scroll_max_speed;  // offset 19
  uint32_t sleep_timeout_ms;  // offset 23
  uint8_t  led_brightness;    // offset 27
  uint16_t blink_interval_ms; // offset 28
  uint8_t  scroll_invert;     // offset 30  0=通常, 1=反転
  uint32_t magic;             // offset 31 = 0x504F5441
};
#pragma pack(pop)

#define CONFIG_VERSION  3
#define CONFIG_MAGIC    0x504F5441UL  // "POTA"

// =========================================================================
// 動作モード
// =========================================================================
enum OperatingMode : uint8_t {
  MODE_USB = 0,
  MODE_BT1 = 1,
  MODE_BT2 = 2,
  MODE_BT3 = 3,
  MODE_COUNT = 4
};

// =========================================================================
// BLE スロット別アドレス・名前
// =========================================================================
static const char* BT_SLOT_NAMES[3] = { "PotaKB-1", "PotaKB-2", "PotaKB-3" };

// ハードウェアUID からスロットごとに固有の Random Static アドレスを生成
void getSlotAddr(uint8_t slot, ble_gap_addr_t* addr) {
  addr->addr_type = BLE_GAP_ADDR_TYPE_RANDOM_STATIC;
  uint32_t uid0 = NRF_FICR->DEVICEID[0];
  uint32_t uid1 = NRF_FICR->DEVICEID[1];
  addr->addr[0] = (uid0      ) & 0xFF;
  addr->addr[1] = (uid0 >>  8) & 0xFF;
  addr->addr[2] = (uid0 >> 16) & 0xFF;
  addr->addr[3] = (uid0 >> 24) & 0xFF;
  addr->addr[4] = (uid1      ) & 0xFF;
  // 上位バイト: bit7:6=11(Random Static必須), bit5:4=スロット番号, bit3:0=UID由来
  addr->addr[5] = 0xC0 | ((slot & 0x03) << 4) | ((uid1 >> 8) & 0x0F);
}

// =========================================================================
// BLE UUID
// =========================================================================
#define KEYMAP_SVC_UUID   "adaf0001-c332-42a8-93bd-25e905756cb8"
#define KEYMAP_CHAR_UUID  "adaf0002-c332-42a8-93bd-25e905756cb8"
#define CONFIG_CHAR_UUID  "adaf0003-c332-42a8-93bd-25e905756cb8"

// =========================================================================
// グローバル変数
// =========================================================================

// --- ハードウェア ---
Adafruit_MCP23X17 mcp;

// --- HID ---
Adafruit_USBD_HID usb_hid;

// USB HID descriptor: keyboard(ID=1) + hi-res mouse(ID=2)
static const uint8_t hid_desc[] = {
  TUD_HID_REPORT_DESC_KEYBOARD(HID_REPORT_ID(1)),
  // Mouse with Resolution Multiplier (hi-res scroll)
  0x05,0x01, 0x09,0x02, 0xA1,0x01,
    0x85,0x02,
    0x09,0x01, 0xA1,0x00,
      0x05,0x09, 0x19,0x01, 0x29,0x05,
      0x15,0x00, 0x25,0x01, 0x95,0x05, 0x75,0x01, 0x81,0x02,
      0x95,0x01, 0x75,0x03, 0x81,0x03,
      0x05,0x01, 0x09,0x30, 0x09,0x31,
      0x16,0x01,0x80, 0x26,0xFF,0x7F,
      0x95,0x02, 0x75,0x10, 0x81,0x06,
      0x09,0x38,
      0xA1,0x02,
        0x05,0x01, 0x09,0x48,
        0x15,0x00, 0x25,0x01, 0x35,0x01, 0x45,0x78,
        0x95,0x01, 0x75,0x02, 0xB1,0x02,
        0x95,0x01, 0x75,0x06, 0xB1,0x03,
        0x05,0x01, 0x09,0x38,
        0x16,0x01,0x80, 0x26,0xFF,0x7F,
        0x35,0x00, 0x45,0x00,
        0x95,0x01, 0x75,0x10, 0x81,0x06,
      0xC0,
    0xC0,
  0xC0,
};

// hi-res mouse report struct (Report ID 2)
struct __attribute__((packed)) UsbMouseReport {
  uint8_t buttons;
  int16_t x, y, wheel;
};

volatile uint8_t g_usb_res_mult = 1;  // 1=通常, 120=hi-res

uint16_t usb_get_report_cb(uint8_t report_id, hid_report_type_t type,
                            uint8_t* buf, uint16_t req_len) {
  if (type == HID_REPORT_TYPE_FEATURE && report_id == 2) {
    buf[0] = (g_usb_res_mult == 120) ? 0x01 : 0x00;
    return 1;
  }
  return 0;
}

void usb_set_report_cb(uint8_t report_id, hid_report_type_t type,
                        uint8_t const* buf, uint16_t len) {
  if (type == HID_REPORT_TYPE_FEATURE && report_id == 2 && len >= 1) {
    g_usb_res_mult = ((buf[0] & 0x03) == 1) ? 120 : 1;
  }
}

// --- BLE ---
BLEDis        bledis;
BLEHidAdafruit blehid;
BLEBas        bas;
BLEService    keymapSvc(KEYMAP_SVC_UUID);
BLECharacteristic keymapChar(KEYMAP_CHAR_UUID);
BLECharacteristic configChar(CONFIG_CHAR_UUID);

// --- 設定・キーマップ ---
Config currentConfig;
uint16_t current_keymap[NUM_LAYERS][LAYOUT_KEY_COUNT];

// --- モード ---
OperatingMode currentMode = MODE_USB;

// --- キーマトリクス ---
// matrix_to_layout[r][c] = レイアウトインデックス (-1=未割当)
int8_t matrix_to_layout[ROWS][COLS];

bool keyState[ROWS][COLS];
bool lastRawKeyState[ROWS][COLS];
unsigned long keyChangeTime[ROWS][COLS];

bool backBtnState = false, nextBtnState = false;
bool lastRawBack = false, lastRawNext = false;
unsigned long backChangeTime = 0, nextChangeTime = 0;

// --- レイヤー ---
uint8_t active_layer = 0;
bool layer_held[NUM_LAYERS];

// --- 前回レポート（変化検出用）---
uint8_t prev_kb_mod = 0;
uint8_t prev_kb_keys[6] = {0};
uint8_t prev_mouse_btn = 0;

// --- スティック（EMAスムージング）---
float smoothed_x = 512.0f;
float smoothed_y = 512.0f;
unsigned long lastStickUpdateTime = 0;

// --- スクロール速度スムージング（カクつき防止）---
float smooth_scroll_v = 0.0f;  // Y軸スクロール速度（EMA後）
float smooth_scroll_h = 0.0f;  // X軸スクロール速度（EMA後）

// --- マウスアキュムレータ ---
float acc_mouse_x = 0.0f;
float acc_mouse_y = 0.0f;
float acc_scroll  = 0.0f;
float acc_pan     = 0.0f;
unsigned long lastMouseReportTime = 0;

// --- モード切替フラグ ---
bool sw_mode_was_pressed = false;

// --- キャリブレーション中フラグ ---
bool calibrating = false;

// --- アクティビティ・スリープ ---
unsigned long lastActivityTime = 0;
bool isSleeping = false;

// --- バッテリー ---
unsigned long lastBatteryTime = 0;
int lastBatteryTier = -1;

// --- BLE 接続インターバル再交渉 ---
unsigned long ble_connect_time    = 0;
unsigned long ble_last_param_req  = 0;
bool          ble_param_needed    = false;
unsigned long ble_switch_done_at  = 0;  // switchMode完了時刻

// --- BLEデータ受信バッファ ---
uint8_t  keymap_buf[sizeof(current_keymap)];
uint16_t keymap_buf_offset = 0;
uint8_t  config_buf[sizeof(Config)];
uint16_t config_buf_offset = 0;

// --- シリアルコマンドバッファ ---
enum SerialState { SER_IDLE, SER_RECV_KEYMAP, SER_RECV_CONFIG };
SerialState serialState = SER_IDLE;
String serialCmdBuf = "";

// =========================================================================
// 関数プロトタイプ
// =========================================================================
void     loadDefaultConfig();
void     loadConfig();
void     saveConfig();
void     loadKeymap();
void     saveKeymap();
OperatingMode loadMode();
void     saveMode(OperatingMode m);

void     initHardware();
bool     initMCP();
void     initBLE();
void     startAdvertising(uint8_t btSlot);

void     scanMatrix();
void     scanDirectKeys();
void     processInputs();
void     updateStick(unsigned long now);
void     sendReports(uint8_t kb_mod, uint8_t kb_keys[6], uint8_t mouse_btn,
                     int8_t mx, int8_t my, int8_t scroll, int8_t pan);

void     switchMode(OperatingMode newMode);
void     updateLED();

void     doCalibrate();
void     doReset();
void     doReboot();

void     updateBattery();

void     handleSerial();

void     goSleep();
void     wakeUp();
void     powerOff();

bool     isAnyActivity();

// BLEコールバック
void onConnect(uint16_t conn_handle);
void onDisconnect(uint16_t conn_handle, uint8_t reason);
void onKeymapWrite(uint16_t conn_hdl, BLECharacteristic* chr, uint8_t* data, uint16_t len);
void onConfigWrite(uint16_t conn_hdl, BLECharacteristic* chr, uint8_t* data, uint16_t len);

// =========================================================================
// setup
// =========================================================================
void setup() {
  // 電源スイッチを最初にチェック（initHardware前 = LED点灯前）
  // USB給電でブートした場合もOFF状態なら起動しない
  pinMode(POWER_SW_PIN, INPUT_PULLUP);
  if (digitalRead(POWER_SW_PIN) == HIGH) {
    // USB接続中はSYSTEMOFFが即リセットを引き起こすが、
    // setup()先頭から再実行されるためLEDは点灯しない
    NRF_POWER->SYSTEMOFF = 1;
    while (1);  // SYSTEMOFF後は来ない（安全のため）
  }

  Serial.begin(115200);

  TinyUSBDevice.setID(0x239A, 0x8029);
  TinyUSBDevice.setManufacturerDescriptor("0Re0_8192");
  TinyUSBDevice.setProductDescriptor("PotaKB");

  InternalFS.begin();

  loadDefaultConfig();
  loadConfig();
  loadKeymap();

  currentMode = loadMode();

  initHardware();
  initBLE();
  updateBattery();

  // USBマウント待ち（2秒）
  {
    unsigned long t = millis();
    while (!TinyUSBDevice.mounted() && millis() - t < 2000) delay(10);
  }

  // モード確定
  // USB接続あり → 保存モードに関わらずUSB優先
  if (TinyUSBDevice.mounted()) {
    currentMode = MODE_USB;
  } else if (currentMode == MODE_USB) {
    currentMode = MODE_BT1;
    saveMode(currentMode);
  }
  switchMode(currentMode);

  lastActivityTime = millis();
  lastStickUpdateTime = millis();
}

// =========================================================================
// loop
// =========================================================================
void loop() {
  // 電源スイッチ
  if (digitalRead(POWER_SW_PIN) == HIGH) powerOff();

  // USBケーブル抜き検出（モードは保存しない：次回USB接続時にUSBで起動できるよう）
  if (currentMode == MODE_USB && !TinyUSBDevice.mounted()) {
    currentMode = MODE_BT1;
    Bluefruit.Advertising.stop();
    startAdvertising(0);
    updateLED();
  }

  // USBケーブル接続検出（BTモード中にUSBを刺した瞬間だけUSBモードへ。手動でBTにしたままUSBを刺し続けた場合は切り替えない）
  static bool prev_usb_mounted = false;
  bool usb_now = TinyUSBDevice.mounted();
  if (currentMode != MODE_USB && usb_now && !prev_usb_mounted) {
    switchMode(MODE_USB);
  }
  prev_usb_mounted = usb_now;

  // BLE 接続インターバル再交渉 (7.5ms = interval 6)
  if (ble_param_needed && Bluefruit.connected()) {
    unsigned long now_ms = millis();
    // switchMode完了から2秒以上経過した接続にのみ要求（切替直後の不安定状態を避ける）
    if (now_ms - ble_switch_done_at >= 2000 &&
        ble_connect_time >= ble_switch_done_at) {
      uint16_t hdl = Bluefruit.connHandle();
      BLEConnection* conn = Bluefruit.Connection(hdl);
      if (conn && ((ble_last_param_req == 0 && now_ms - ble_connect_time >= 1000) ||
                   (ble_last_param_req != 0 && now_ms - ble_last_param_req >= 10000))) {
        conn->requestConnectionParameter(6, 0, 200);
        ble_last_param_req = now_ms;
      }
    }
  }

  // シリアルコマンド処理
  if (Serial.available()) handleSerial();

  // キースキャン
  scanMatrix();
  scanDirectKeys();

  // 入力処理・レポート送信
  processInputs();

  // スリープ管理（BTモードのみ）
  if (currentMode != MODE_USB) {
    if (isSleeping) {
      if (isAnyActivity()) wakeUp();
      else waitForEvent();
      return;
    }
    if (millis() - lastActivityTime > currentConfig.sleep_timeout_ms) {
      goSleep();
    }
  }

  // バッテリー更新
  if (millis() - lastBatteryTime > 60000UL) {
    updateBattery();
    lastBatteryTime = millis();
  }

  updateLED();
}

// =========================================================================
// initHardware
// =========================================================================
void initHardware() {
  // LED
  pinMode(LED_BUILTIN, INPUT);
  pinMode(LED_RED,   OUTPUT); pinMode(LED_GREEN, OUTPUT); pinMode(LED_BLUE, OUTPUT);
  analogWrite(LED_RED, 255); analogWrite(LED_GREEN, 255); analogWrite(LED_BLUE, 255);

  pinMode(POWER_LED_PIN, OUTPUT);
  analogWrite(POWER_LED_PIN, currentConfig.led_brightness);

  pinMode(BT_LED_PIN, OUTPUT);
  analogWrite(BT_LED_PIN, 0);

  // ボタン・スイッチ
  pinMode(BACK_BTN_PIN, INPUT_PULLUP);
  pinMode(NEXT_BTN_PIN, INPUT_PULLUP);
  pinMode(POWER_SW_PIN, INPUT_PULLUP);
  nrf_gpio_cfg_sense_input(
    digitalPinToPinName(POWER_SW_PIN),
    NRF_GPIO_PIN_PULLUP,
    NRF_GPIO_PIN_SENSE_LOW
  );

  // USB HID
  usb_hid.setPollInterval(1);
  usb_hid.setReportDescriptor(hid_desc, sizeof(hid_desc));
  usb_hid.setReportCallback(usb_get_report_cb, usb_set_report_cb);
  usb_hid.begin();

  // MCP23017
  if (!initMCP()) {
    // 初期化失敗: 赤LED高速点滅でエラー通知
    Serial.println("ERROR: MCP23017 init failed");
    for (int i = 0; i < 10; i++) {
      analogWrite(LED_RED, 0); delay(100);
      analogWrite(LED_RED, 255); delay(100);
    }
  }
  Wire.setClock(400000);

  // マトリクス → レイアウトインデックス変換テーブル構築
  buildMatrixMap();

  // スムージング初期化
  smoothed_x = currentConfig.stick_center_x;
  smoothed_y = currentConfig.stick_center_y;
}

// =========================================================================
// マトリクスマップ構築
// sw番号(1-64) → マトリクス座標 の変換テーブル
// =========================================================================
void buildMatrixMap() {
  memset(matrix_to_layout, -1, sizeof(matrix_to_layout));

  // sw番号(1-based) → [row, col]
  static const uint8_t sw_to_rc[64][2] = {
    {0,0},{0,1},{0,2},{0,3},{1,1},{1,2},{1,3},{0,4},
    {2,1},{2,2},{2,3},{1,4},{3,1},{3,2},{3,3},{2,4},
    {4,1},{4,2},{4,3},{3,4},{5,1},{5,2},{5,3},{4,4},
    {6,1},{6,2},{6,3},{5,4},{4,5},{7,1},{7,2},{7,3},
    {6,4},{5,5},{1,0},{1,5},{3,6},{7,4},{6,5},{2,0},
    {2,5},{0,7},{4,7},{4,6},{3,0},{3,5},{1,7},{5,7},
    {5,6},{4,0},{0,6},{2,7},{6,7},{6,6},{5,0},{1,6},
    {7,5},{7,7},{6,0},{2,6},{3,7},{7,0},{0,5},{0,0}
  };

  // 物理レイアウト順（sw番号 1-based、63個）
  static const uint8_t layout_order[LAYOUT_KEY_COUNT - 2] = {
     1, 62,  2,  5,  9, 13, 17, 21, 25, 30, 35, 40, 45, 50, 55,
    59, 63,  3,  6, 10, 14, 18, 22, 26, 31, 36, 41, 46, 51, 56,
    60,  4,  7, 11, 15, 19, 23, 27, 32, 37, 42, 47, 52, 57, 61,
     8, 12, 16, 20, 24, 28, 33, 38, 43, 48, 53, 58, 29, 34, 39,
    44, 49, 54
  };

  for (int i = 0; i < (LAYOUT_KEY_COUNT - 2); i++) {
    int sw = layout_order[i];
    int r  = sw_to_rc[sw - 1][0];
    int c  = sw_to_rc[sw - 1][1];
    matrix_to_layout[r][c] = i;
  }
}

// =========================================================================
// MCP23017初期化
// =========================================================================
bool initMCP() {
  // I2Cバスリカバリ: SDAがLOWで詰まっている場合に9クロックで解放
  {
    const int SDA_PIN = SDA;
    const int SCL_PIN = SCL;
    pinMode(SCL_PIN, OUTPUT);
    pinMode(SDA_PIN, INPUT_PULLUP);
    if (digitalRead(SDA_PIN) == LOW) {
      for (int i = 0; i < 9; i++) {
        digitalWrite(SCL_PIN, HIGH); delayMicroseconds(5);
        digitalWrite(SCL_PIN, LOW);  delayMicroseconds(5);
      }
      // STOP condition
      pinMode(SDA_PIN, OUTPUT);
      digitalWrite(SDA_PIN, LOW);  delayMicroseconds(5);
      digitalWrite(SCL_PIN, HIGH); delayMicroseconds(5);
      digitalWrite(SDA_PIN, HIGH); delayMicroseconds(5);
    }
    // Wire に引き渡す
    Wire.begin();
  }

  if (!mcp.begin_I2C()) return false;
  for (int i = 0; i < 8;  i++) mcp.pinMode(i, INPUT_PULLUP);
  for (int i = 8; i < 16; i++) mcp.pinMode(i, OUTPUT);
  mcp.writeGPIOAB(0xFFFF);
  return true;
}

// =========================================================================
// scanMatrix
// =========================================================================
void scanMatrix() {
  unsigned long now = millis();
  for (int c = 0; c < COLS; c++) {
    mcp.writeGPIOAB(~(1u << (c + 8)));
    delayMicroseconds(5);
    uint16_t gpio = mcp.readGPIOAB();
    for (int r = 0; r < ROWS; r++) {
      bool raw = !(gpio & (1u << r));
      if (raw != lastRawKeyState[r][c]) keyChangeTime[r][c] = now;
      lastRawKeyState[r][c] = raw;
      if (now - keyChangeTime[r][c] > DEBOUNCE_MS) keyState[r][c] = raw;
    }
  }
  mcp.writeGPIOAB(0xFFFF);
}

// =========================================================================
// scanDirectKeys
// =========================================================================
void scanDirectKeys() {
  unsigned long now = millis();

  bool rawNext = (digitalRead(NEXT_BTN_PIN) == LOW);
  if (rawNext != lastRawNext) nextChangeTime = now;
  lastRawNext = rawNext;
  if (now - nextChangeTime > DEBOUNCE_MS) nextBtnState = rawNext;

  bool rawBack = (digitalRead(BACK_BTN_PIN) == LOW);
  if (rawBack != lastRawBack) backChangeTime = now;
  lastRawBack = rawBack;
  if (now - backChangeTime > DEBOUNCE_MS) backBtnState = rawBack;
}

// =========================================================================
// レイヤー解決
// キーコードを取得する（KC_TRNSなら下のレイヤーに透過）
// =========================================================================
uint16_t resolveKey(uint8_t layer, int idx) {
  uint16_t key = current_keymap[layer][idx];
  if (key == KC_TRNS && layer > 0) {
    key = current_keymap[0][idx];
  }
  return key;
}
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

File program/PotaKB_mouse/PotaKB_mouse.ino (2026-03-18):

// =========================================================================
// PotaKB Mouse fw v1
// MCP23017 キーマトリクスなし・マウスのみ
//
// 目的: キースキャンのI2Cオーバーヘッドを排除してマウスHzを計測・改善する
//
// ボタン:
//   BACK (D6) ホールド → スクロールモード
//   NEXT (D10) タップ  → BLEスロット切替
//
// LED:
//   緑固定       → USBモード
//   青固定/点滅  → BTモード (固定=接続中, 点滅=アドバタイズ中)
//
// シリアル (115200):
//   1秒ごとに "Hz=XXX" を出力 (マウスレポート送信頻度)
// =========================================================================

#include <bluefruit.h>
#include <Adafruit_TinyUSB.h>
#include <InternalFileSystem.h>
#include "types.h"

using namespace Adafruit_LittleFS_Namespace;

// =========================================================================
// ピン定義
// =========================================================================
#define STICK_PHYS_X_PIN  A2   // PCBミス: 物理XピンがY動作
#define STICK_PHYS_Y_PIN  A3   // PCBミス: 物理YピンがX動作
#define BACK_BTN_PIN      D6
#define NEXT_BTN_PIN      D10
#define POWER_SW_PIN      D7
#define POWER_LED_PIN     D0
#define BT_LED_PIN        D1

#define DEBOUNCE_MS       5

// =========================================================================
// 設定構造体 (PotaKB_fw と同一バイナリ互換)
// =========================================================================
#pragma pack(push, 1)
struct Config {
  uint8_t  version;
  uint16_t stick_center_x;
  uint16_t stick_center_y;
  uint16_t stick_deadzone;
  uint16_t stick_range_x;
  uint16_t stick_range_y;
  float    stick_ema_alpha;
  float    mouse_max_speed;
  float    scroll_max_speed;
  uint32_t sleep_timeout_ms;
  uint8_t  led_brightness;
  uint16_t blink_interval_ms;
  uint8_t  scroll_invert;
  uint32_t magic;
};
#pragma pack(pop)

#define CONFIG_VERSION  3
#define CONFIG_MAGIC    0x504F5441UL

static const char* CONFIG_FILE = "/config.bin";
static const char* MODE_FILE   = "/mode.bin";

// デフォルト値
#define DEFAULT_STICK_CENTER_X    512
#define DEFAULT_STICK_CENTER_Y    512
#define DEFAULT_STICK_DEADZONE    40
#define DEFAULT_STICK_RANGE_X     450
#define DEFAULT_STICK_RANGE_Y     450
#define DEFAULT_STICK_EMA_ALPHA   0.4f
#define DEFAULT_MOUSE_MAX_SPEED   0.5f
#define DEFAULT_SCROLL_MAX_SPEED  0.02f
#define DEFAULT_SLEEP_TIMEOUT_MS  300000UL
#define DEFAULT_LED_BRIGHTNESS    50
#define DEFAULT_BLINK_INTERVAL_MS 500
#define DEFAULT_SCROLL_INVERT     0

// =========================================================================
// USB HID - hi-res マウス (Report ID 1)
// test_hiresscroll v5 と同一 descriptor
// =========================================================================
static const uint8_t desc_hid_usb[] = {
  0x05, 0x01,        // Usage Page (Generic Desktop)
  0x09, 0x02,        // Usage (Mouse)
  0xA1, 0x01,        // Collection (Application)
    0x85, 0x01,      //   Report ID (1)
    0x09, 0x01,      //   Usage (Pointer)
    0xA1, 0x00,      //   Collection (Physical)
      0x05, 0x09,    //     Usage Page (Button)
      0x19, 0x01, 0x29, 0x05,
      0x15, 0x00, 0x25, 0x01,
      0x95, 0x05, 0x75, 0x01, 0x81, 0x02,
      0x95, 0x01, 0x75, 0x03, 0x81, 0x03,
      0x05, 0x01,    //     Usage Page (Generic Desktop)
      0x09, 0x30, 0x09, 0x31,
      0x16, 0x01, 0x80, 0x26, 0xFF, 0x7F,
      0x95, 0x02, 0x75, 0x10, 0x81, 0x06,
      0x09, 0x38,    //     Usage (Wheel)
      0xA1, 0x02,    //     Collection (Logical)
        0x05, 0x01, 0x09, 0x48,
        0x15, 0x00, 0x25, 0x01, 0x35, 0x01, 0x45, 0x78,
        0x95, 0x01, 0x75, 0x02, 0xB1, 0x02,
        0x95, 0x01, 0x75, 0x06, 0xB1, 0x03,
        0x05, 0x01, 0x09, 0x38,
        0x16, 0x01, 0x80, 0x26, 0xFF, 0x7F,
        0x35, 0x00, 0x45, 0x00,
        0x95, 0x01, 0x75, 0x10, 0x81, 0x06,
      0xC0,
    0xC0,
  0xC0,
};

struct __attribute__((packed)) UsbMouseReport {
  uint8_t buttons;
  int16_t x, y, wheel;
};

Adafruit_USBD_HID usb_hid;
volatile uint8_t g_usb_res_mult = 1;  // 1 or 120

uint16_t usb_get_report_cb(uint8_t report_id, hid_report_type_t type,
                            uint8_t* buf, uint16_t req_len) {
  if (type == HID_REPORT_TYPE_FEATURE && report_id == 1) {
    buf[0] = (g_usb_res_mult == 120) ? 0x01 : 0x00;
    return 1;
  }
  return 0;
}

void usb_set_report_cb(uint8_t report_id, hid_report_type_t type,
                        uint8_t const* buf, uint16_t len) {
  if (type == HID_REPORT_TYPE_FEATURE && report_id == 1 && len >= 1) {
    g_usb_res_mult = ((buf[0] & 0x03) == 1) ? 120 : 1;
  }
}

// =========================================================================
// BLE
// =========================================================================
BLEDis        bledis;
BLEHidGeneric blehid(1, 0, 1);  // 1 input (mouse), 0 output, 1 feature (res multiplier)
BLEBas        bas;

volatile uint8_t g_ble_res_mult = 1;  // 1 or 120

void ble_feature_cb(uint16_t conn_hdl, BLECharacteristic* chr, uint8_t* data, uint16_t len) {
  (void) conn_hdl; (void) chr;
  if (len >= 1) {
    g_ble_res_mult = ((data[0] & 0x03) == 1) ? 120 : 1;
    Serial.print("BLE hi-res: "); Serial.println(g_ble_res_mult);
  }
}

// =========================================================================
// グローバル変数
// =========================================================================
Config        currentConfig;
OperatingMode currentMode = MODE_USB;

float smoothed_x, smoothed_y;
float smooth_scroll_v = 0.0f;
unsigned long lastStickUpdateTime = 0;

float acc_mouse_x = 0.0f, acc_mouse_y = 0.0f;
float acc_scroll  = 0.0f, acc_pan     = 0.0f;
unsigned long lastMouseReportTime = 0;

bool backBtnState = false, nextBtnState = false;
bool lastRawBack  = false, lastRawNext  = false;
unsigned long backChangeTime = 0, nextChangeTime = 0;
bool nextWasPressed = false;  // エッジ検出

bool isSleeping = false;
unsigned long lastActivityTime = 0;
unsigned long lastBatteryTime  = 0;
int lastBatteryTier = -1;

// Hz 計測
uint32_t      hz_count = 0;
unsigned long hz_start = 0;

// BLE 接続間隔再交渉
unsigned long ble_connect_time  = 0;
unsigned long ble_last_param_req = 0;
bool          ble_param_needed  = false;

// =========================================================================
// 関数プロトタイプ
// =========================================================================
void loadDefaultConfig();
void loadConfig();
void saveConfig();
OperatingMode loadMode();
void saveMode(OperatingMode m);
void initHardware();
void initBLE();
void startAdvertising(uint8_t slot);
void switchMode(OperatingMode m);
void scanDirectKeys();
void updateStick(unsigned long now);
void sendMouseReport(unsigned long now);
void updateLED();
void updateBattery();
void goSleep();
void wakeUp();
void powerOff();
bool isAnyActivity();
void onConnect(uint16_t conn_handle);
void onDisconnect(uint16_t conn_handle, uint8_t reason);
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

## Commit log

2026-03-17 feat: v2.0 firmware & configurator rewrite
    Firmware (PotaKB_fw.ino / keymap.h):
    - Fix mouse jitter: velocity × deltaTime approach (consistent across BLE/USB)
    - Fix stick axis inversion bug: explicit A2→logicY, A3→logicX mapping
    - Fix layer transparency bug: KC_TRNS=0xFFFF, KC_NO=0x0000 (were same value)
    - Fix accumulator overflow causing reverse direction: constrain(-127,127)
    - Add BT1/BT2/BT3 + USB 4-mode switching with Flash persistence
    - Add EMA smoothing (replaces ring buffer, no OOB risk)
    - Add on-device stick calibration via KC_CALIBRATE key
    - Add BLE HID appearance in advertising packet
    - QMK-style MO(n) layer keys
    Configurator (PotaKB_Configurator/):
    - Full rewrite: dark theme,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
    [L.3mf, L.stl, Potable_Keyboard.step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]
2026-03-17 Docs: セッション管理システム導入
    - Claude/CLAUDE.md: プロジェクト仕様・設計決定サマリ
    - Claude/CLOSING.md: セッション終了処理手順
    - Claude/PROGRESS.md: 進捗管理・v2.0完了状態を記録
    - Claude/extract_session.py: JSONL→テキスト変換スクリプト
    - Claude/session_close.py: セッション終了自動化スクリプト
    - Claude/chat_logs/原文/index.md: セッション索引
2026-03-18 Docs: session01終了処理・セッション管理システム導入・extract_session.pyパス修正
2026-03-18 Docs: session03終了処理・PROGRESS/index/CLAUDE.md更新
2026-03-18 Feat: BLE多スロット・USB hi-resスクロール・コンフィグレーター改善
    - BLE 3スロット対応（PotaKB-1/2/3、スロット別ランダムスタティックアドレス）
    - スロット別ボンドDBディレクトリ（同一PC複数スロット接続のボンド競合を解消）
    - BLE接続Hz向上（BANDWIDTH_MAX / hvn_qsize=3 → ~500Hz）
    - BLE接続インターバル再交渉（7.5ms、レース条件対策済み）
    - USB HID Resolution Multiplier によるhi-resスクロール
    - スロット別LEDカラー（BT1=青、BT2=水色、BT3=マゼンタ）
    - スクロール開始遅延の修正（EMA即時キックスタート）
    - BT中にUSBを刺したら自動USB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
    [PotaKB_fw.ino, PotaKB_mouse.ino, keymap.h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]
2026-03-18 Fix: スリープ復帰後にマウス・キーボードが動かない問題を修正
    スリープ中にlastStickUpdateTimeが止まったまま起床すると
    dtが巨大になりaccumulatorが瞬時にMAXに達してマウスが暴走していた。
    wakeUp()でアキュムレータ・スティック時刻・前回レポート状態をリセット。
    [PotaKB_fw.ino]
2026-03-18 Docs: README更新（ビルド環境・機能一覧・Configurator説明を最新化）
2026-03-18 Docs: session05終了処理・PROGRESS/index/CLAUDE.md更新
